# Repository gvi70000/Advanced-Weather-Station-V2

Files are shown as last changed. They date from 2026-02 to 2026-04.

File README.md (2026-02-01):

Advanced Weather Station V2
The Advanced Weather Station V2 is a high-precision environmental monitoring system designed for professional-grade reliability and scientific accuracy. Building upon the success of the first version, V2 introduces significant hardware optimizations and a more powerful processing architecture to deliver even better performance in the field.
TOP
BOTTOM

Key Improvements in V2
Upgraded MCU: Now powered by the STM32G431, providing enhanced processing capabilities, better power efficiency, and advanced peripherals compared to the previous generation.

Streamlined Communication: All Programmable Gain Amplifiers (PGAs) are now consolidated on a single UART bus, simplifying the communication protocol and reducing cable complexity.

Enhanced PCB Design: A completely overhauled PCB layout featuring improved signal integrity, better thermal management, and a more compact, robust form factor for long-term outdoor deployment.

Overview
This weather station integrates a comprehensive suite of high-precision sensors to monitor atmospheric conditions, air quality, and spatial positioning. It leverages ultrasonic technology for maintenance-free wind measurement and GNSS RTK for centimetre-level location accuracy.

Features & Sensors
Ultrasonic Wind Measurement: Precise wind speed and direction without moving parts.

GNSS RTK: High-precision positioning for mobile or stationary research.

Environmental Suite:

UV & Ambient Light: UV radiation and light intensity monitoring.

Air Quality: ScioSense ENS160 for CO2 and VOC detection.

Lightning Detection: ScioSense AS3935 for storm activity tracking.

Pressure & Temp: Bosch BMP581 for barometric accuracy.

Humidity: Dual TI HDC3020 sensors for redundant climate analysis.

Rugged Construction: Optical sensors are protected by UV-transparent glass, and the ultrasonic assembly uses 304 stainless steel and ASA 3D-printed enclosures.

Workflow
Data Acquisition: Sensors collect raw environmental data, including wind vectors, gas concentrations, and radiation levels.

Processing: The STM32G431 aggregates the data, applies calibration constants, and handles temperature compensation in real-time.

Connectivity: Processed data is transmitted via an ESP32-PoE interface to Ethernet networks, enabling seamless integration with MQTT brokers or cloud-based dashboards.

Applications
Climate & Scientific Research: Accurate data collection for long-term studies.

Smart Agriculture: Optimize irrigation and crop protection based on hyper-local weather.

Renewable Energy: Ideal for solar tracking and wind farm site assessment.

Smart Cities: Real-time air quality and environmental safety monitoring.

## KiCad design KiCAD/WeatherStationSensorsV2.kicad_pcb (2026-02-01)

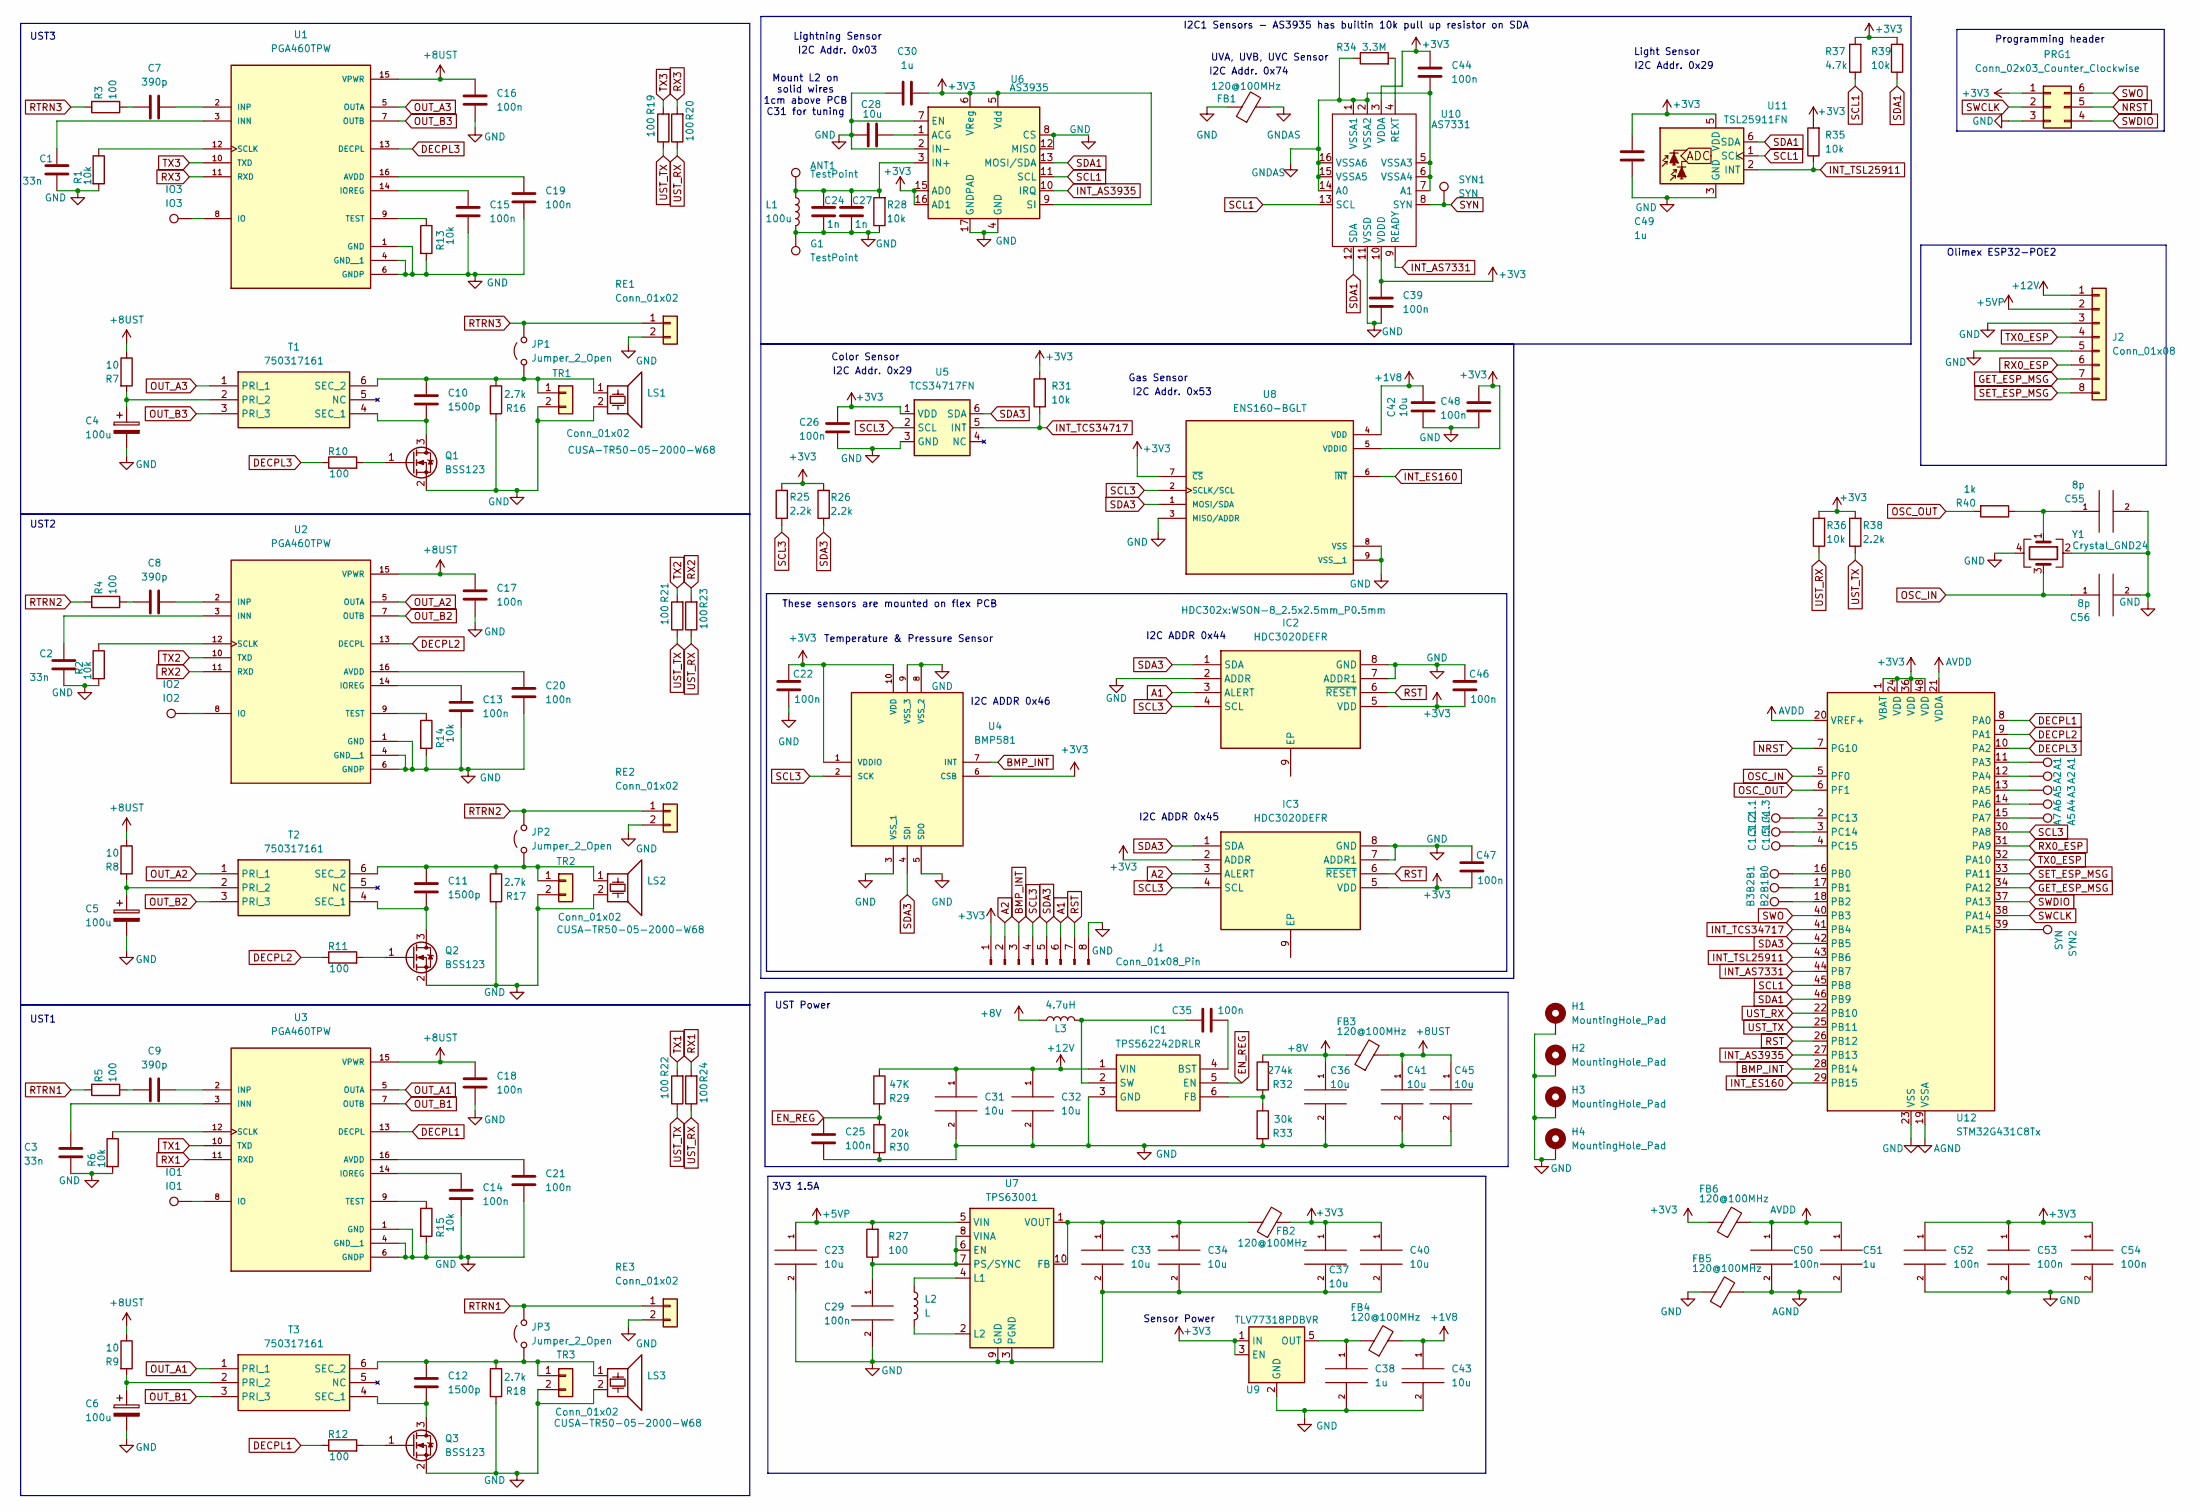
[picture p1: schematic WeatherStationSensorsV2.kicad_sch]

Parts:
A1: A1; TestPoint_Pad_D1.0mm
A2: A2; TestPoint_Pad_D1.0mm
A3: A5; TestPoint_Pad_D1.0mm
A4: A6; TestPoint_Pad_D1.0mm
A5: A7; TestPoint_Pad_D1.0mm
ANT1: TestPoint; TestPoint_THTPad_D1.5mm_Drill0.7mm
B1: B0; TestPoint_Pad_D1.0mm
B2: B1; TestPoint_Pad_D1.0mm
B3: B2; TestPoint_Pad_D1.0mm
C1, C2, C3: 33n; C_0805_2012Metric_Pad1.18x1.45mm_HandSolder
C1.1: C1.3; TestPoint_Pad_D1.0mm
C1.2: C1.4; TestPoint_Pad_D1.0mm
C1.3: C1.5; TestPoint_Pad_D1.0mm
C4, C5, C6: 100u; CP_Radial_D8.0mm_P3.50mm
C7, C8, C9: 390p; C_0805_2012Metric_Pad1.18x1.45mm_HandSolder
C10, C11, C12: 1500p; C_0805_2012Metric_Pad1.18x1.45mm_HandSolder
C13, C14, C15, C16, C17, C18, C19, C20, C21, C25, C26, C29, C35, C39, C44, C48, C50, C52, C53, C54: 100n; C_0805_2012Metric_Pad1.18x1.45mm_HandSolder
C22, C46, C47: 100n; C_0805_2012Metric
C23, C31, C32, C33, C34, C36, C37, C40, C41, C43, C45: 10u; C_1210_3225Metric_Pad1.33x2.70mm_HandSolder
C24, C27: 1n; C_0805_2012Metric_Pad1.18x1.45mm_HandSolder
C28, C42: 10u; C_0805_2012Metric_Pad1.18x1.45mm_HandSolder
C30, C38, C49, C51: 1u; C_0805_2012Metric_Pad1.18x1.45mm_HandSolder
C55, C56: 8p; C_0603_1608Metric_Pad1.08x0.95mm_HandSolder
FB1, FB2, FB3, FB4, FB5, FB6: 120@100MHz; R_0805_2012Metric_Pad1.20x1.40mm_HandSolder
G1: TestPoint; TestPoint_THTPad_D1.5mm_Drill0.7mm
H1, H2, H3, H4: MountingHole_Pad; MountingHole_3.2mm_M3_Pad_Via
IC1: TPS562242DRLR; SOTFL50P160X60-6N; Manufacturer_Part_Number TPS562242DRLR
IC2, IC3: HDC3020DEFR; WSON-8_2.5x2.5mm_P0.5mm; Mouser Part Number 595-HDC3020DEFR
IO1: IO1; TestPoint_Pad_D1.0mm
IO2: IO2; TestPoint_Pad_D1.0mm
IO3: IO3; TestPoint_Pad_D1.0mm
J1: Conn_01x08_Pin; Hirose_DF13-08P-1.25DSA_1x08_P1.25mm_Vertical
J2: Conn_01x08; PinHeader_1x08_P2.54mm_Vertical
JP1, JP2, JP3: Jumper_2_Open; SolderJumper-2_P1.3mm_Open_RoundedPad1.0x1.5mm
L1: 100u; Coilcraft_MA5532-AE_RFID
L2: L; CC453232A
L3: 4.7uH; L_Bourns_SDR0703-4R7KL
LS1, LS2, LS3: CUSA-TR50-05-2000-W68
PRG1: Conn_02x03_Counter_Clockwise; PinHeader_2x03_P2.54mm_Vertical
Q1, Q2, Q3: BSS123; SOT-23
R1, R2, R6, R13, R14, R15, R31, R35, R36, R39: 10k; R_0805_2012Metric_Pad1.20x1.40mm_HandSolder
R3, R4, R5, R10, R11, R12, R19, R20, R21, R22, R23, R24, R27: 100; R_0805_2012Metric_Pad1.20x1.40mm_HandSolder
R7, R8, R9: 10; R_0805_2012Metric_Pad1.20x1.40mm_HandSolder
R16, R17, R18: 2.7k; R_0805_2012Metric_Pad1.20x1.40mm_HandSolder
R25, R26, R38: 2.2k; R_0805_2012Metric_Pad1.20x1.40mm_HandSolder
R28: 10k; R_0603_1608Metric_Pad0.98x0.95mm_HandSolder
R29: 47K; R_0805_2012Metric_Pad1.20x1.40mm_HandSolder
R30: 20k; R_0805_2012Metric_Pad1.20x1.40mm_HandSolder
R32: 274k; R_0805_2012Metric_Pad1.20x1.40mm_HandSolder
R33: 30k; R_0805_2012Metric_Pad1.20x1.40mm_HandSolder
R34: 3.3M; R_0805_2012Metric_Pad1.20x1.40mm_HandSolder
R37: 4.7k; R_0805_2012Metric_Pad1.20x1.40mm_HandSolder
R40: 1k; R_0603_1608Metric_Pad0.98x0.95mm_HandSolder
RE1, RE2, RE3: Conn_01x02; PinHeader_1x02_P2.54mm_Vertical
SYN1, SYN2: SYN; TestPoint_Pad_D1.0mm
T1, T2, T3: 750317161; Mouser Part Number 710-750317161
TR1, TR2, TR3: Conn_01x02; PinHeader_1x02_P2.54mm_Vertical
U1, U2, U3: PGA460TPW; SOP65P640X120-16N; PARTREV B
U4: BMP581; Manufacturer_Part_Number BMP581
U5: TCS34717FN; FN6
U6: AS3935; MLPQ-16-1EP_4x4mm_P0.65mm_EP2.8x2.8mm
U7: TPS63001; Texas_DRC0010J_ThermalVias
U8: ENS160-BGLT; XDCR_ENS160-BGLT; PARTREV 1.3
U9: TLV77318PDBVR; SOT-23-5
U10: AS7331
U11: TSL25911FN; AMS_TSL25911FN
U12: STM32G431C8Tx; LQFP-48_7x7mm_P0.5mm
Y1: Crystal_GND24; Crystal_SMD_3225-4Pin_3.2x2.5mm_HandSoldering

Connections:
+1V8: C42.2, C43.1, FB4.2, U8.4 (VDD)
+3V3: C22.1, C26.1, C30.2, C37.1, C39.1, C40.1, C44.1, C46.2, C47.2, C48.1, C49.2, C52.1, C53.1, C54.1, FB2.2, FB6.1, IC2.5 (VDD), IC3.2 (ADDR), IC3.5 (VDD), J1.1, PRG1.1, R25.2, R26.2, R31.2, R35.2, R36.2, R37.2, R38.2, R39.2, U4.1 (VDDIO), U4.6 (CSB), U4.10 (VDD), U5.1 (VDD), U6.5 (Vdd), U6.6 (VReg), U6.9 (SI), U6.15 (AD0), U6.16 (AD1), U8.5 (VDDIO), U8.7 (~CS), U9.1 (IN), U9.3 (EN), U10.3 (VDDA), U10.10 (VDDD), U11.5 (VDD), U12.1 (VBAT), U12.24 (VDD), U12.36 (VDD), U12.48 (VDD)
+5VP: C23.1, J2.2, R27.2, U7.5 (VIN)
+8UST: C16.1, C17.1, C18.1, C41.1, C45.1, FB3.2, R7.1, R8.1, R9.1, U1.15 (VPWR), U2.15 (VPWR), U3.15 (VPWR)
+8V: C36.1, FB3.1, L3.1, R32.1
+12V: C31.1, C32.1, IC1.1 (VIN), J2.1, R29.1
A1: IC2.3 (ALERT), J1.6
A2: IC3.3 (ALERT), J1.2
AGND: C50.2, C51.2, FB5.2, U12.19 (VSSA)
AVDD: C50.1, C51.1, FB6.2, U12.20 (VREF+), U12.21 (VDDA)
BMP_INT: J1.3, U4.7 (INT), U12.28 (PB14)
DECPL1: R12.1, U3.13 (DECPL), U12.8 (PA0)
DECPL2: R11.1, U2.13 (DECPL), U12.9 (PA1)
DECPL3: R10.1, U1.13 (DECPL), U12.10 (PA2)
EN_REG: C25.1, IC1.5 (EN), R29.2, R30.1
GET_ESP_MSG: J2.7, U12.34 (PA12)
GND: C1.1, C2.1, C3.1, C4.2, C5.2, C6.2, C13.2, C14.2, C15.2, C16.2, C17.2, C18.2, C19.2, C20.2, C21.2, C22.2, C23.2, C24.2, C25.2, C26.2, C27.2, C28.2, C29.2, C30.1, C31.2, C32.2, C33.2, C34.2, C36.2, C37.2, C38.2, C39.2, C40.2, C41.2, C42.1, C43.2, C45.2, C46.1, C47.1, C48.2, C49.1, C52.2, C53.2, C54.2, C55.2, C56.2, FB1.1, FB5.1, G1.1, H1.1, H2.1, H3.1, H4.1, IC1.3 (GND), IC2.2 (ADDR), IC2.7 (ADDR1), IC2.8 (GND), IC3.7 (ADDR1), IC3.8 (GND), J1.8, J2.3, J2.5, L1.2, LS1.2, LS2.2, LS3.2, PRG1.3, Q1.2 (S), Q2.2 (S), Q3.2 (S), R1.2, R2.2, R6.2, R13.2, R14.2, R15.2, R16.2, R17.2, R18.2, R28.1, R30.2, R33.2, RE1.2, RE2.2, RE3.2, TR1.2, TR2.2, TR3.2, U1.1 (GND), U1.4 (GND__1), U1.6 (GNDP), U2.1 (GND), U2.4 (GND__1), U2.6 (GNDP), U3.1 (GND), U3.4 (GND__1), U3.6 (GNDP), U4.3 (VSS_1), U4.5 (SDO), U4.8 (VSS_2), U4.9 (VSS_3), U5.3 (GND), U6.2 (IN-), U6.4 (GND), U6.7 (EN), U6.8 (CS), U6.12 (MISO), U6.17 (GNDPAD), U7.3 (PGND), U7.9 (GND), U7.11 (PGND), U8.3 (MISO/ADDR), U8.8 (VSS), U8.9 (VSS__1), U9.2 (GND), U10.11 (VSSD), U11.3 (GND), U12.23 (VSS), U12.35 (VSS), U12.47 (VSS), Y1.2, Y1.4
GNDAS: C44.2, FB1.2, R34.1, U10.1 (VSSA1), U10.2 (VSSA2), U10.5 (VSSA3), U10.6 (VSSA4), U10.7 (A1), U10.14 (A0), U10.15 (VSSA5), U10.16 (VSSA6)
INT_AS3935: U6.10 (IRQ), U12.27 (PB13)
INT_AS7331: U10.9 (READY), U12.44 (PB7)
INT_ES160: U8.6 (~INT), U12.29 (PB15)
INT_TCS34717: R31.1, U5.5 (INT), U12.41 (PB4)
INT_TSL25911: R35.1, U11.2 (INT), U12.43 (PB6)
NRST: PRG1.5, U12.7 (PG10)
unnamed: C7.2, R3.1
unnamed: C8.2, R4.1
unnamed: C9.2, R5.1
unnamed: C55.1, R40.1, Y1.1
unnamed: C35.2, IC1.4 (BST)
unnamed: IC1.6 (FB), R32.2, R33.1
unnamed: C35.1, IC1.2 (SW), L3.2
unnamed: C10.1, JP1.1 (A), LS1.1, R16.1, T1.6 (SEC_2), TR1.1
unnamed: C11.1, JP2.1 (A), LS2.1, R17.1, T2.6 (SEC_2), TR2.1
unnamed: C12.1, JP3.1 (A), LS3.1, R18.1, T3.6 (SEC_2), TR3.1
unnamed: C10.2, Q1.3 (D), T1.4 (SEC_1)
unnamed: Q1.1 (G), R10.2
unnamed: C11.2, Q2.3 (D), T2.4 (SEC_1)
unnamed: Q2.1 (G), R11.2
unnamed: C12.2, Q3.3 (D), T3.4 (SEC_1)
unnamed: Q3.1 (G), R12.2
unnamed: C4.1, R7.2, T1.2 (PRI_2)
unnamed: C5.1, R8.2, T2.2 (PRI_2)
unnamed: C6.1, R9.2, T3.2 (PRI_2)
unnamed: C19.1, U1.16 (AVDD)
unnamed: C1.2, U1.3 (INN)
unnamed: C7.1, U1.2 (INP)
unnamed: IO3.1, U1.8 (IO)
unnamed: C15.1, U1.14 (IOREG)
unnamed: R1.1, U1.12 (SCLK)
unnamed: R13.1, U1.9 (TEST)
unnamed: C20.1, U2.16 (AVDD)
unnamed: C2.2, U2.3 (INN)
unnamed: C8.1, U2.2 (INP)
unnamed: IO2.1, U2.8 (IO)
unnamed: C13.1, U2.14 (IOREG)
unnamed: R2.1, U2.12 (SCLK)
unnamed: R14.1, U2.9 (TEST)
unnamed: C21.1, U3.16 (AVDD)
unnamed: C3.2, U3.3 (INN)
unnamed: C9.1, U3.2 (INP)
unnamed: IO1.1, U3.8 (IO)
unnamed: C14.1, U3.14 (IOREG)
unnamed: R6.1, U3.12 (SCLK)
unnamed: R15.1, U3.9 (TEST)
unnamed: C28.1, U6.1 (ACG)
unnamed: ANT1.1, C24.1, C27.1, L1.1, R28.2, U6.3 (IN+)
unnamed: C29.1, R27.1, U7.6 (EN), U7.7 (PS/SYNC), U7.8 (VINA)
unnamed: C33.1, C34.1, FB2.1, U7.1 (VOUT), U7.10 (FB)
unnamed: L2.1, U7.4 (L1)
unnamed: L2.2, U7.2 (L2)
unnamed: C38.1, FB4.1, U9.5 (OUT)
unnamed: R34.2, U10.4 (REXT)
unnamed: A1.1, U12.11 (PA3)
unnamed: A2.1, U12.12 (PA4)
unnamed: A3.1, U12.13 (PA5)
unnamed: A4.1, U12.14 (PA6)
unnamed: A5.1, U12.15 (PA7)
unnamed: SYN2.1, U12.39 (PA15)
unnamed: B1.1, U12.16 (PB0)
unnamed: B2.1, U12.17 (PB1)
unnamed: B3.1, U12.18 (PB2)
unnamed: C1.1.1, U12.2 (PC13)
unnamed: C1.2.1, U12.3 (PC14)
unnamed: C1.3.1, U12.4 (PC15)
OSC_IN: C56.1, U12.5 (PF0), Y1.3
OSC_OUT: R40.2, U12.6 (PF1)
OUT_A1: T3.1 (PRI_1), U3.5 (OUTA)
OUT_A2: T2.1 (PRI_1), U2.5 (OUTA)
OUT_A3: T1.1 (PRI_1), U1.5 (OUTA)
OUT_B1: T3.3 (PRI_3), U3.7 (OUTB)
OUT_B2: T2.3 (PRI_3), U2.7 (OUTB)
OUT_B3: T1.3 (PRI_3), U1.7 (OUTB)
RST: IC2.6 (~RESET), IC3.6 (~RESET), J1.7, U12.26 (PB12)
RTRN1: JP3.2 (B), R5.2, RE3.1
RTRN2: JP2.2 (B), R4.2, RE2.1
RTRN3: JP1.2 (B), R3.2, RE1.1
RX0_ESP: J2.6, U12.31 (PA9)
RX1: R24.2, U3.11 (RXD)
RX2: R23.2, U2.11 (RXD)
RX3: R20.2, U1.11 (RXD)
SCL1: R37.1, U6.11 (SCL), U10.13 (SCL), U11.1 (SCL), U12.45 (PB8)
SCL3: IC2.4 (SCL), IC3.4 (SCL), J1.4, R25.1, U4.2 (SCK), U5.2 (SCL), U8.2 (SCLK/SCL), U12.30 (PA8)
SDA1: R39.1, U6.13 (MOSI/SDA), U10.12 (SDA), U11.6 (SDA), U12.46 (PB9)
SDA3: IC2.1 (SDA), IC3.1 (SDA), J1.5, R26.1, U4.4 (SDI), U5.6 (SDA), U8.1 (MOSI/SDA), U12.42 (PB5)
SET_ESP_MSG: J2.8, U12.33 (PA11)
SWCLK: PRG1.2, U12.38 (PA14)
SWDIO: PRG1.4, U12.37 (PA13)
SWO: PRG1.6, U12.40 (PB3)
SYN: SYN1.1, U10.8 (SYN)
TX0_ESP: J2.4, U12.32 (PA10)
TX1: R22.2, U3.10 (TXD)
TX2: R21.2, U2.10 (TXD)
TX3: R19.2, U1.10 (TXD)
UST_RX: R20.1, R23.1, R24.1, R36.1, U12.22 (PB10)
UST_TX: R19.1, R21.1, R22.1, R38.1, U12.25 (PB11)

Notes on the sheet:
3V3 1.5A
These sensors are mounted on flex PCB
UST1
I2C Addr. 0x74
UST2
Gas Sensor
I2C Addr. 0x53
Mount L2 on solid wires 1cm above PCB C31 for tuning
Lightning Sensor
I2C ADDR 0x45
Sensor Power
Temperature & Pressure Sensor
I2C ADDR 0x44
Programming header
I2C Addr. 0x03
UST3
Light Sensor
UVA, UVB, UVC Sensor
I2C1 Sensors - AS3935 has builtin 10k pull up resistor on SDA
I2C Addr. 0x29
Olimex ESP32-POE2
UST Power
I2C ADDR 0x46
Color Sensor

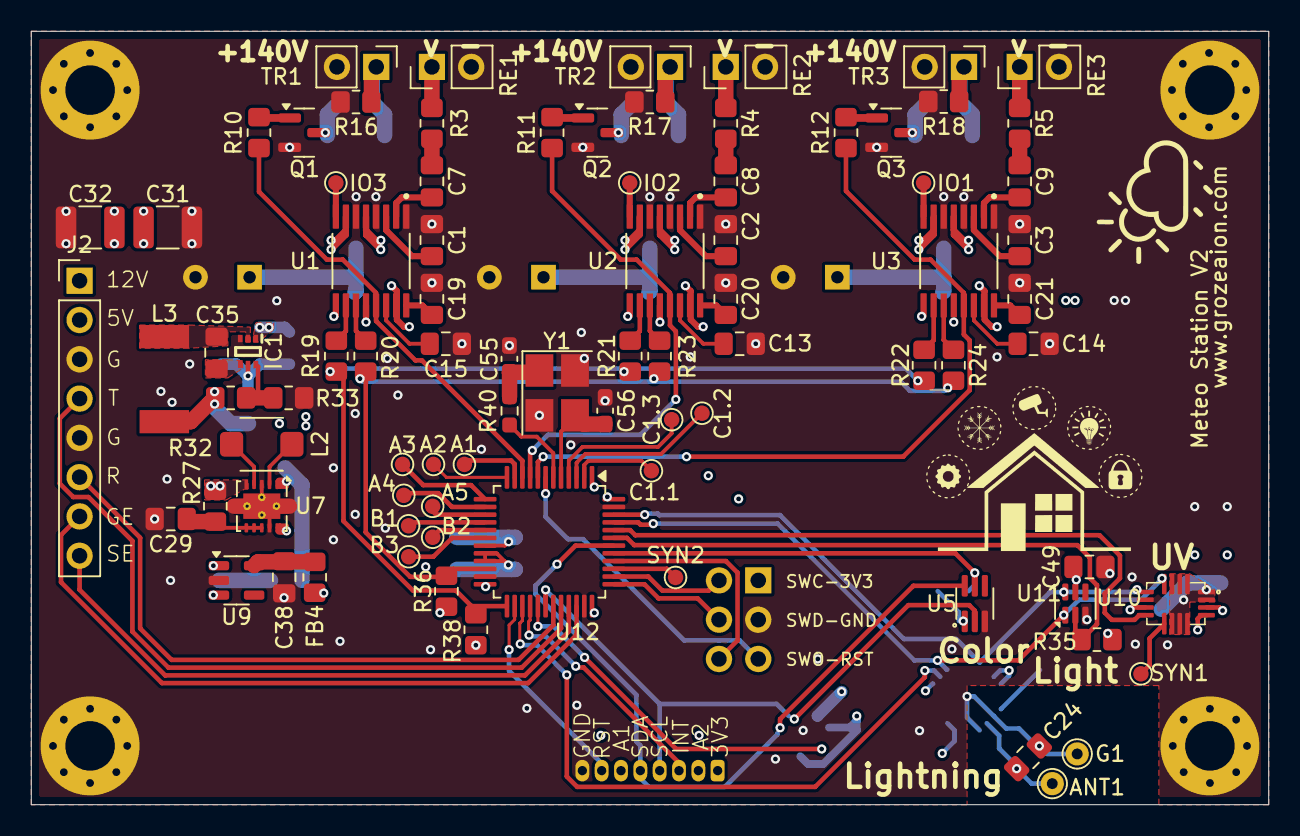
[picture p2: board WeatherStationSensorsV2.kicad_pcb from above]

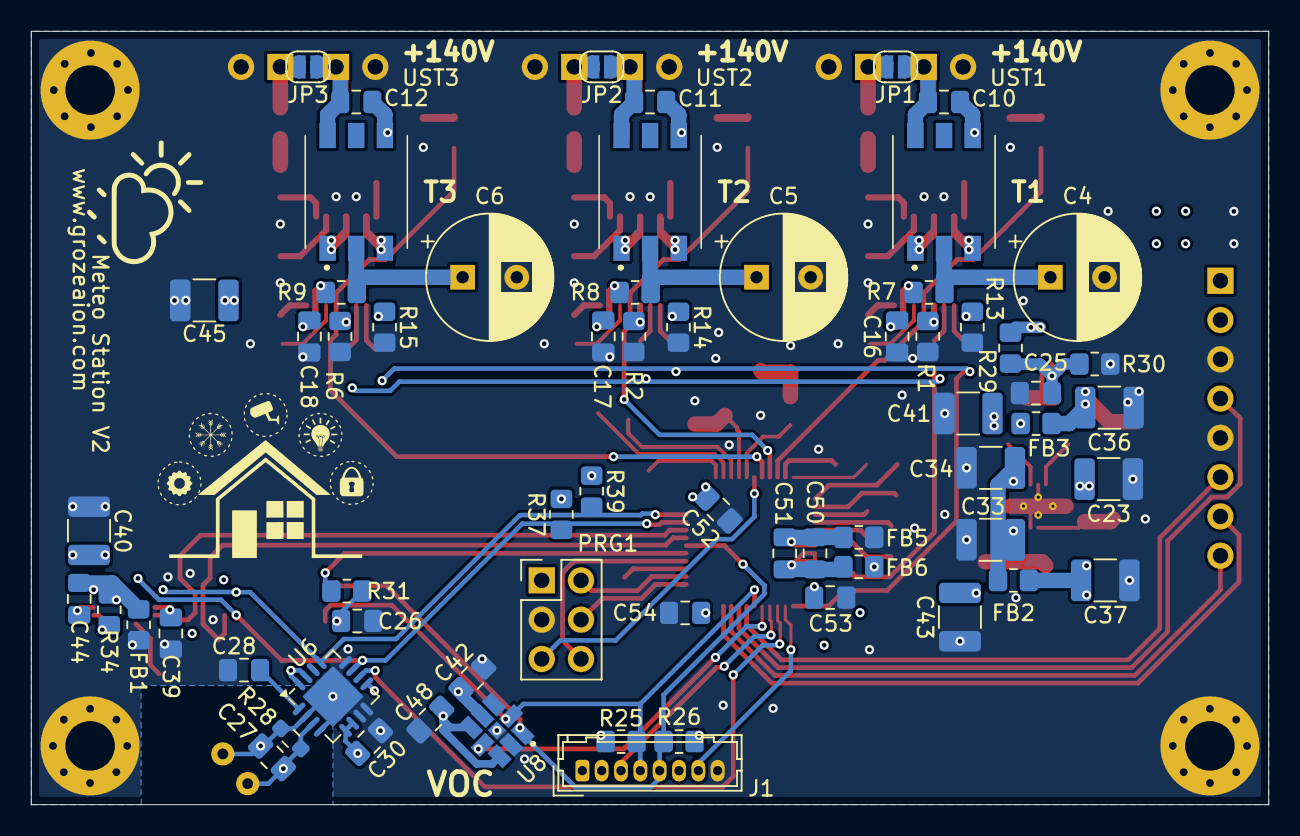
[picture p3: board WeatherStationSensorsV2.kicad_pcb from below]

Board: 4 copper layers, 80.0 x 50.0 mm, 154 parts (65 on the bottom side), 113 nets.

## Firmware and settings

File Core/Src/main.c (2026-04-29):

/**
  ******************************************************************************
  * @file           : main.c
  * @brief          : Main program body
  ******************************************************************************
  * @attention
  *
  * Copyright (c) 2026 STMicroelectronics.
  * All rights reserved.
  *
  * This software is licensed under terms that can be found in the LICENSE file
  * in the root directory of this software component.
  * If no LICENSE file comes with this software, it is provided AS-IS.
  *
  ******************************************************************************
  */
/* USER CODE END Header */
/* Includes ------------------------------------------------------------------*/
#include "main.h"
#include "cordic.h"
#include "dma.h"
#include "i2c.h"
#include "tim.h"
#include "usart.h"
#include "gpio.h"

/* USER CODE BEGIN Includes */
#include <stdio.h>
#include <string.h>
#include <math.h>
/* I2C3 sensors */
#include "BMP581.h"
#include "HDC302x.h"
#include "TCS34003.h"
#include "ENS160.h"
/* I2C1 sensors */
#include "TSL25911.h"
#include "AS7331.h"
#include "AS3935.h"
#include "PGA460.h"
#include "Wind.h"
#include "debug.h"
/* USER CODE END Includes */

/* USER CODE BEGIN PM */

/* =========================================================================
 * Sensor ready bitmasks
 * ======================================================================= */
#define SENSOR_ENV        (1u << 0)  /* BMP581 + HDC302x environmental data  */
#define SENSOR_AS7331     (1u << 1)  /* UV sensor                             */
#define SENSOR_ENS160     (1u << 2)  /* Air quality                           */
#define SENSOR_TCS34003   (1u << 3)  /* RGB colour                            */
#define SENSOR_TSL25911   (1u << 4)  /* Ambient light                         */
#define SENSOR_WIND       (1u << 5)  /* Wind (disabled — commented out below) */
#define SENSOR_AS3935     (1u << 6)  /* Lightning (preserved across frames)   */

/* Bits that must ALL be set before a sensor data frame is sent to the ESP.
 * SENSOR_WIND (bit 5) is excluded while wind measurement is disabled.
 * SENSOR_AS3935 (bit 6) is excluded — lightning is asynchronous and is
 * preserved in the payload until a new event overwrites it.               */
#define SENSOR_FRAME_MASK  0x1Fu     /* bits 0–4: ENV|AS7331|ENS160|TCS|TSL  */

/* =========================================================================
 * STM32 -> ESP  UART frame protocol
 *
 * Frame A — Sensor data (68 bytes):
 *   [0x23][0x40][Payload(64)][CRC16(2)]
 *   SOF = { 0x23, 0x40 }  (Start + Length byte, 0x40 = 64)
 *   CRC covers Payload only (64 bytes).
 *
 * Frame B — Wind calibration readback (17 bytes):
 *   [0x23][0x24][0x0C][D01(4)][D12(4)][D20(4)][CRC16(2)]
 *   SOF = { 0x23, 0x24 }  (Start + FrameType CAL)
 *   CRC covers Length byte + 3 x uint32 = 13 bytes.
 * ======================================================================= */
#define UART_FRAME_START   0x23u   /* '#'  first SOF byte for both TX frames  */
#define UART_FRAME_CAL     0x24u   /* '$'  second SOF byte for calibration TX */

/* =========================================================================
 * ESP -> STM  UART frame protocol
 *
 * Single frame type — 20 bytes:
 *   [0x23][FrameType(1)][Wind_Input_t(16)][CRC16(2)]
 *   CRC covers FrameType + Wind_Input_t = 17 bytes.
 *
 * FrameType values:
 *   0x24  UART_FRAME_CAL      Boot-time: ESP sends Height + D01/D12/D20 from NVS
 *   0x25  UART_FRAME_TMP      Height field carries float temperature reference (°C)
 *   0x26  UART_FRAME_RH       Height field carries float RH reference (%)
 *   0x27  UART_FRAME_RST      System reset request (Wind_Input_t payload ignored)
 *   0x28  UART_FRAME_CAL_REQ  Run Wind_CalibrateReflector() request
 * ======================================================================= */
#define UART_FRAME_TMP      0x25u   /* '%' temperature reference              */
#define UART_FRAME_RH       0x26u   /* '&' RH reference                       */
#define UART_FRAME_RST      0x27u   /* ''' reset                              */
#define UART_FRAME_CAL_REQ  0x28u   /* '(' calibration run request            */

/* ESP->STM frame size = Start(1) + FrameType(1) + Wind_Input_t(16) + CRC(2) */
#define UART_ESP_RX_SIZE   20u

/* =========================================================================
 * AS3935 interrupt type encoding in DistanceEstimation byte
 *
 * The AS3935_LightningData_t.DistanceEstimation byte carries two fields:
 *   Bits [5:0]  = distance code  (AS3935_Distance_t, 0x3F = out of range)
 *   Bits [7:4]  = interrupt type (AS3935_INT_t: 0x01=NH, 0x04=D, 0x08=L)
 *
 * Bits [7:6] of the raw register are reserved/always-zero per datasheet,
 * so packing the INT type there is non-destructive and backward-compatible
 * with any ESP code that masks off the upper nibble before reading distance.
 *
 * Helper macros:
 *   AS3935_ENCODE_DIST(irq, dist)  — pack for the wire
 *   AS3935_DECODE_INT(byte)        — extract INT type
 *   AS3935_DECODE_DIST(byte)       — extract distance code
 * ======================================================================= */
#define AS3935_ENCODE_DIST(irq, dist)  ((uint8_t)(((uint8_t)(irq) << 4) | ((dist) & 0x3Fu)))
#define AS3935_DECODE_INT(byte)        (((byte) >> 4) & 0x0Fu)
#define AS3935_DECODE_DIST(byte)       ((byte) & 0x3Fu)

/* =========================================================================
 * PID / sensor filtering constants
 * ======================================================================= */
#define DT_SEC             1.0f
#define TEMP_DEADBAND      0.2f
#define RH_DEADBAND        0.5f
#define MAX_TEMP_STEP      0.2f
#define MAX_RH_STEP        0.5f
#define TEMP_OFFSET_MIN   -1.0f
#define TEMP_OFFSET_MAX    1.0f
#define RH_OFFSET_MIN    -3.0f
#define RH_OFFSET_MAX     3.0f

/* USER CODE END PM */


/* USER CODE BEGIN PV */
/* Data-ready flags set by HAL_GPIO_EXTI_Callback (gpio.c) */
extern volatile uint8_t AS3935_Ready;
extern volatile uint8_t AS7331_Ready;
extern volatile uint8_t ENS160_Ready;
extern volatile uint8_t BMP_Ready;
extern volatile uint8_t TCS34003_Ready;
extern volatile uint8_t TSL25911_Ready;
extern volatile uint8_t ESP_Transmitting;

volatile uint8_t sensorReadyFlags = 0;

/* Shared environmental data — written by main loop, read by Wind.c */
extern Wind_EnvData_t externalData;

/* Sensor data structs */
BMP581_sensor_data_t BMP581_Data;
HDC302x_t            Sensor1;
HDC302x_t            Sensor2;
ENS160_Resistance_t  ENS160_Resistance;

/* Wind calibration data: Height, PathLenD01, PathLenD12, PathLenD20 */
extern Wind_Input_t calibData;

/* =========================================================================
 * UART_Payload_t — 64 bytes, must match ESP UART_Payload_t exactly.
 *
 * TCS34003: full TCS34003_LightData_t (22 B) is sent — RGBC(8) + IR(2)
 * + CCT(4) + Lux(4) + Irradiance(4).  All fields computed on STM and
 * published by ESP to individual MQTT topics.
 *
 * AS3935 note: LightningData_t.DistanceEstimation encodes both the INT type
 * (bits [7:4]) and the distance code (bits [5:0]).  See AS3935_ENCODE_DIST.
 * ======================================================================= */
typedef struct __attribute__((packed)) {
    Wind_EnvData_t       Env;          /* 20 B: Temp, RH, Pressure, DewPt, SndSpd */
    Wind_t               Wind;         /*  8 B: Speed (f32), Direction (f32)        */
    AS3935_LightningData_t Lightning;  /*  5 B: Energy (u32), DistanceEstimation(u8)*/
    AS7331_DataOut_t     UV;           /*  8 B: TEMP_C100, UVA, UVB, UVC (u16 x4)  */
    ENS160_Data_t        AirQuality;   /*  5 B: AQI (u8), TVOC (u16), eCO2 (u16)   */
    TCS34003_LightData_t LightRGB;     /* 22 B: RGBC(8)+IR(2)+CCT(4)+Lux(4)+Irr(4) */
    TSL25911_LightData_t Light;        /* 10 B: FS, IR, Vis (u16 x3), Lux (f32)    */
} UART_Payload_t;                      /* = 64 bytes total                          */

_Static_assert(sizeof(UART_Payload_t) == 78u,
    "UART_Payload_t size mismatch with ESP — check struct members");

/* =========================================================================
 * STM -> ESP sensor data frame.
 * Wire:  [0x23][0x4E][Payload(78)][CRC16(2)]  = 82 bytes.
 * ======================================================================= */
typedef struct __attribute__((packed)) {
    uint8_t        Start;    /* 0x23                              */
    uint8_t        Length;   /* sizeof(UART_Payload_t) = 64=0x40 */
    UART_Payload_t Payload;
    uint16_t       CR;       /* CRC16 over Payload only           */
} UART_TX_Frame_t;

_Static_assert(sizeof(UART_TX_Frame_t) == 82u,
    "UART_TX_Frame_t size mismatch with ESP");

/* =========================================================================
 * STM -> ESP calibration frame (after Wind_CalibrateReflector).
 * Wire:  [0x23][0x24][0x0C][D01(4)][D12(4)][D20(4)][CRC16(2)]  = 17 bytes.
 * CRC covers: Length(1) + D01(4) + D12(4) + D20(4) = 13 bytes.
 * ======================================================================= */
typedef struct __attribute__((packed)) {
    uint8_t  Start;       /* UART_FRAME_START 0x23          */
    uint8_t  FrameType;   /* UART_FRAME_CAL   0x24          */
    uint8_t  Length;      /* 3 * sizeof(uint32_t) = 12      */
    uint32_t PathLenD01;
    uint32_t PathLenD12;
    uint32_t PathLenD20;
    uint16_t CR;
} UART_TX_Cal_Frame_t;

_Static_assert(sizeof(UART_TX_Cal_Frame_t) == 17u,
    "UART_TX_Cal_Frame_t size mismatch");

/* =========================================================================
 * ESP -> STM command frame (all types share this layout).
 * Wire:  [0x23][FrameType(1)][Wind_Input_t(16)][CRC16(2)]  = 20 bytes.
 * CRC covers: FrameType(1) + Wind_Input_t(16) = 17 bytes.
 * ======================================================================= */
typedef struct __attribute__((packed)) {
    uint8_t      Start;      /* UART_FRAME_START 0x23                      */
    uint8_t      FrameType;  /* 0x24..0x28 — selects action                */
    Wind_Input_t Payload;    /* Wind_Input_t: Height(4), D01(4),D12(4),D20(4) */
    uint16_t     CR;         /* CRC16 over FrameType + Wind_Input_t        */
} UART_RX_Frame_t;

_Static_assert(sizeof(UART_RX_Frame_t) == 20u,
    "UART_RX_Frame_t size mismatch");

/* DMA buffers */
static UART_TX_Frame_t  txFrameBuf;
static uint8_t          espRxBuf[UART_ESP_RX_SIZE];

/* Runtime state */
static float            temperatureCalibrated = 0.0f;
static float            humidityCalibrated    = 0.0f;
static uint8_t          isReset               = 0;
static volatile uint8_t isCalibrate           = 0;
volatile uint8_t        dmaTxBusy             = 0;  /* extern in usart.c */
uint32_t                time                  = 0;

typedef struct {
    float kp, ki, kd;
    float integral;
    float prevError;
    float outMin, outMax;
    float errAvg;
    float errVar;
} PID_t;

PID_t pidTemp1 = { .kp = 0.3f,  .ki = 0.05f, .kd = 0.1f,  .outMin = -5.0f,  .outMax = 5.0f  };
PID_t pidTemp2 = { .kp = 0.3f,  .ki = 0.05f, .kd = 0.1f,  .outMin = -5.0f,  .outMax = 5.0f  };
PID_t pidRH    = { .kp = 0.2f,  .ki = 0.02f, .kd = 0.05f, .outMin = -10.0f, .outMax = 10.0f };

/* USER CODE END PV */

void SystemClock_Config(void);
/* USER CODE BEGIN 0 */

/* -------------------------------------------------------------------------
 * CRC16 (Modbus) — matches the ESP implementation exactly.
 * ---------------------------------------------------------------------- */
static uint16_t CRC16(const uint8_t *data, uint16_t len) {
    uint16_t crc = 0xFFFFu;
    for (uint16_t i = 0; i < len; i++) {
        crc ^= data[i];
        for (uint8_t j = 0; j < 8u; j++) {
            crc = (crc & 1u) ? ((crc >> 1) ^ 0xA001u) : (crc >> 1);
        }
    }
    return crc;
}

/* -------------------------------------------------------------------------
 * SendDataToESP — non-blocking DMA TX.
 *
 * Wire frame: [0x23][0x4E][Payload(78)][CRC16(2)] = 82 bytes.
 * The ESP processSTMbyte() syncs on the two-byte sequence {0x23, 0x4E}.
 * STM_START_TX asserts SET_ESP_MSG so the ESP backs off (FIX-3 on ESP side).
 * dmaTxBusy is cleared in HAL_UART_TxCpltCallback (usart.c) on DMA complete.
 * ---------------------------------------------------------------------- */
void SendDataToESP(void) {
    if (dmaTxBusy) return;
    txFrameBuf.CR = CRC16((const uint8_t *)&txFrameBuf.Payload,
                          sizeof(UART_Payload_t));
    dmaTxBusy = 1;
    STM_START_TX;
    HAL_UART_Transmit_DMA(&huart1, (uint8_t *)&txFrameBuf,
                          sizeof(UART_TX_Frame_t));
}
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
int main(void)
{

  /* MCU Configuration--------------------------------------------------------*/
  HAL_Init();

  /* Configure the system clock */
  SystemClock_Config();

  /* Initialize all configured peripherals */
  MX_GPIO_Init();
  MX_DMA_Init();
  MX_USART1_UART_Init();
  MX_TIM2_Init();
  MX_USART3_UART_Init();
  MX_I2C1_Init();
  MX_I2C3_Init();
  MX_CORDIC_Init();

  /* USER CODE BEGIN 2 */
#ifdef AS3935_MODE_IRQ
    Enable_EXTI_AS3935();
#endif /* AS3935_MODE_IRQ */

    /* Initialise TX frame fixed header fields */
    txFrameBuf.Start  = UART_FRAME_START;
    txFrameBuf.Length = (uint8_t)sizeof(UART_Payload_t);   /* 78 = 0x4E */

    /* Start DMA RX from ESP in circular mode — TC interrupt only */
    HAL_UART_Receive_DMA(&huart1, espRxBuf, UART_ESP_RX_SIZE);
    __HAL_DMA_DISABLE_IT(huart1.hdmarx, DMA_IT_HT);

    /* HDC302x temperature / humidity sensors */
    Sensor1.Address = HDC302X_SENSOR_1_ADDR;
    if (HDC302x_Init(&Sensor1) != HAL_OK) {
        DEBUG("Sensor 1 init failed!\n");
    } else {
        DEBUG("Sensor 1 init OK.\n");
    }
    Sensor2.Address = HDC302X_SENSOR_2_ADDR;
    if (HDC302x_Init(&Sensor2) != HAL_OK) {
        DEBUG("Sensor 2 init failed!\n");
    } else {
        DEBUG("Sensor 2 init OK.\n");
    }
    HDC302x_StartAutoMeasurement(&Sensor1, HDC302X_CMD_AUTO_MEASUREMENT_1_PER_SECOND_LPM0);
    HDC302x_StartAutoMeasurement(&Sensor2, HDC302X_CMD_AUTO_MEASUREMENT_1_PER_SECOND_LPM0);

    /* BMP581 pressure / temperature (interrupt-driven) */
    if (BMP581_Init() == HAL_OK) {
        DEBUG("BMP581 init OK!\n");
    } else {
        DEBUG("BMP581 init FAIL!\n");
    }

    /* ENS160 air quality */
    if (ENS160_Init() != HAL_OK) {
        DEBUG("ENS160 init failed!\n");
    }

    /* AS3935 lightning sensor */
    if (AS3935_Init() != HAL_OK) {
        DEBUG("AS3935 init failed!\n");
    }
#ifdef AS3935_MODE_CALIB
    else {
        /* Antenna tuning: TIM2 CH4 is configured for input capture in
         * CALIB mode.  Start the timer base then run the sweep.        */
        HAL_TIM_Base_Start(&htim2);
        DEBUG("_______________________\n");
        AS3935_TuneCap_t bestCap = AS3935_TuneAntenna();
        AS3935_SetTuningCapacitor(bestCap);
        HAL_TIM_Base_Stop(&htim2);
        DEBUG("AS3935 tuning done, cap=%d\n", (int)bestCap);
    }
#endif /* AS3935_MODE_CALIB */

    /* UV, colour and ambient light sensors */
    if (AS7331_Init()   != HAL_OK) { DEBUG("AS7331 init failed!\n");   }
    if (TCS34003_Init() != HAL_OK) { DEBUG("TCS34003 init failed!\n"); }
    if (TSL25911_Init() != HAL_OK) { DEBUG("TSL25911 init failed!\n"); }

    /* Wind measurement — uncomment when PGA460 hardware is fitted */
    /* PGA460_Init(0); */
    /* Wind_Init();    */

    time = HAL_GetTick();
  /* USER CODE END 2 */

  /* Infinite loop */
  /* USER CODE BEGIN WHILE */
  while (1)
  {
        /* --- System reset requested by ESP --- */
        if (isReset) {
            HAL_Delay(10);
            __NVIC_SystemReset();
        }

        /* --- Wind calibration requested by ESP (MQTT) --- */
        if (isCalibrate) {
            isCalibrate = 0;
            DEBUG("Calibration requested by ESP\n");
            if (Wind_CalibrateReflector() == HAL_OK) {
                SendCalibrationToESP();
            } else {
                DEBUG("Calibration FAILED\n");
            }
        }

        /* --- BMP581 + HDC302x (~1 Hz, BMP interrupt-driven) --- */
        if (BMP_Ready) {
            BMP_Ready = 0;
            float temp1 = 0.0f, temp2 = 0.0f, rh1 = 0.0f, rh2 = 0.0f;
            static float prevOutT1  = 0.0f, prevOutT2  = 0.0f;
            static float prevOutRH1 = 0.0f, prevOutRH2 = 0.0f;

            BMP581_Get_TempPressData(&BMP581_Data);
            if (HDC302x_ReadData(&Sensor1) == HAL_OK) { temp1 = Sensor1.Data.Temperature; rh1 = Sensor1.Data.Humidity; }
            if (HDC302x_ReadData(&Sensor2) == HAL_OK) { temp2 = Sensor2.Data.Temperature; rh2 = Sensor2.Data.Humidity; }

            /* Temperature PID */
            float tempRef = (temperatureCalibrated != 0.0f) ? temperatureCalibrated : BMP581_Data.temperature;
            float errT1 = tempRef - temp1; if (fabsf(errT1) < TEMP_DEADBAND) errT1 = 0.0f;
            float errT2 = tempRef - temp2; if (fabsf(errT2) < TEMP_DEADBAND) errT2 = 0.0f;
            float outT1 = PID_Update_Adaptive(&pidTemp1, errT1, DT_SEC);
            float outT2 = PID_Update_Adaptive(&pidTemp2, errT2, DT_SEC);
            float dT1 = outT1 - prevOutT1;
            if (dT1 >  MAX_TEMP_STEP) outT1 = prevOutT1 + MAX_TEMP_STEP;
            if (dT1 < -MAX_TEMP_STEP) outT1 = prevOutT1 - MAX_TEMP_STEP;
            float dT2 = outT2 - prevOutT2;
            if (dT2 >  MAX_TEMP_STEP) outT2 = prevOutT2 + MAX_TEMP_STEP;
            if (dT2 < -MAX_TEMP_STEP) outT2 = prevOutT2 - MAX_TEMP_STEP;
            prevOutT1 = outT1; prevOutT2 = outT2;
            if (outT1 > TEMP_OFFSET_MAX) outT1 = TEMP_OFFSET_MAX;
            if (outT1 < TEMP_OFFSET_MIN) outT1 = TEMP_OFFSET_MIN;
            if (outT2 > TEMP_OFFSET_MAX) outT2 = TEMP_OFFSET_MAX;
            if (outT2 < TEMP_OFFSET_MIN) outT2 = TEMP_OFFSET_MIN;

            /* Humidity PID */
            float rhRef = (humidityCalibrated != 0.0f) ? humidityCalibrated : (rh1 + rh2) * 0.5f;
            float errRH1 = rhRef - rh1; if (fabsf(errRH1) < RH_DEADBAND) errRH1 = 0.0f;
            float errRH2 = rhRef - rh2; if (fabsf(errRH2) < RH_DEADBAND) errRH2 = 0.0f;
            float outRH1 = PID_Update_Adaptive(&pidRH, errRH1, DT_SEC);
            float outRH2 = PID_Update_Adaptive(&pidRH, errRH2, DT_SEC);
            float dRH1 = outRH1 - prevOutRH1;
            if (dRH1 >  MAX_RH_STEP) outRH1 = prevOutRH1 + MAX_RH_STEP;
            if (dRH1 < -MAX_RH_STEP) outRH1 = prevOutRH1 - MAX_RH_STEP;
            float dRH2 = outRH2 - prevOutRH2;
            if (dRH2 >  MAX_RH_STEP) outRH2 = prevOutRH2 + MAX_RH_STEP;
            if (dRH2 < -MAX_RH_STEP) outRH2 = prevOutRH2 - MAX_RH_STEP;
            prevOutRH1 = outRH1; prevOutRH2 = outRH2;
            if (outRH1 > RH_OFFSET_MAX) outRH1 = RH_OFFSET_MAX;
            if (outRH1 < RH_OFFSET_MIN) outRH1 = RH_OFFSET_MIN;
            if (outRH2 > RH_OFFSET_MAX) outRH2 = RH_OFFSET_MAX;
            if (outRH2 < RH_OFFSET_MIN) outRH2 = RH_OFFSET_MIN;

            HDC302x_SetOffset(&Sensor1, outT1, outRH1);
            HDC302x_SetOffset(&Sensor2, outT2, outRH2);

            txFrameBuf.Payload.Env.Temperature = (temp1 + outT1 + temp2 + outT2) * 0.5f;
            txFrameBuf.Payload.Env.RH          = (rh1 + outRH1 + rh2 + outRH2) * 0.5f;
            txFrameBuf.Payload.Env.Pressure    = BMP581_Data.pressure;

            ENS160_SetEnvCompensation(txFrameBuf.Payload.Env.Temperature,
                                      txFrameBuf.Payload.Env.RH);

            externalData.Temperature = txFrameBuf.Payload.Env.Temperature;
            externalData.RH          = txFrameBuf.Payload.Env.RH;
            externalData.Pressure    = txFrameBuf.Payload.Env.Pressure;
            Wind_ComputeSoundSpeed();
            txFrameBuf.Payload.Env.DewPoint   = externalData.DewPoint;
            txFrameBuf.Payload.Env.SoundSpeed = externalData.SoundSpeed;

            sensorReadyFlags |= SENSOR_ENV;
        }

        /* --- AS3935 lightning sensor (EXTI interrupt-driven) ---
         *
         * AS3935_GetInterruptType() reads the INT register and handles the
         * mandatory >= 2 ms post-IRQ delay internally.
         *
         * All three interrupt types are forwarded to the ESP so it can publish
         * each event to its own MQTT topic.  The interrupt type is packed into
         * bits [7:4] of DistanceEstimation (bits [5:0] carry the distance code;
         * bits [7:6] are reserved-zero in the raw register).
         *
         * INT_L  (0x08) — real lightning strike: read energy + distance.
         * INT_D  (0x04) — disturber detected: no valid distance, send 0x3F.
         * INT_NH (0x01) — noise floor too high: no valid distance, send 0x3F.
         *
         * SENSOR_AS3935 is set on every interrupt so the ESP receives an
         * up-to-date event in the next regular sensor frame.
         * The flag is preserved (not cleared) after each frame send so the
         * last lightning reading persists in the payload until overwritten.  */
        if (AS3935_Ready) {
            AS3935_Ready = 0;
            AS3935_INT_t irqType = AS3935_GetInterruptType();
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

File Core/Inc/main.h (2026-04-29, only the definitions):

#define TIMEOUT_COMM            100 // Timeout for sending ModBus frames
#define DECPL0_Pin GPIO_PIN_0
#define DECPL0_GPIO_Port GPIOA
#define DECPL1_Pin GPIO_PIN_1
#define DECPL1_GPIO_Port GPIOA
#define DECPL2_Pin GPIO_PIN_2
#define DECPL2_GPIO_Port GPIOA
#define INT_AS3935_Pin GPIO_PIN_3
#define INT_AS3935_GPIO_Port GPIOA
#define INT_AS3935_EXTI_IRQn EXTI3_IRQn
#define SGN_Pin GPIO_PIN_5
#define SGN_GPIO_Port GPIOA
#define UST_RX_Pin GPIO_PIN_10
#define UST_RX_GPIO_Port GPIOB
#define UST_TX_Pin GPIO_PIN_11
#define UST_TX_GPIO_Port GPIOB
#define RST_HDC_Pin GPIO_PIN_12
#define RST_HDC_GPIO_Port GPIOB
#define BMP_INT_Pin GPIO_PIN_14
#define BMP_INT_GPIO_Port GPIOB
#define BMP_INT_EXTI_IRQn EXTI15_10_IRQn
#define INT_ES160_Pin GPIO_PIN_15
#define INT_ES160_GPIO_Port GPIOB
#define INT_ES160_EXTI_IRQn EXTI15_10_IRQn
#define ESP_RX_Pin GPIO_PIN_9
#define ESP_RX_GPIO_Port GPIOA
#define ESP_TX_Pin GPIO_PIN_10
#define ESP_TX_GPIO_Port GPIOA
#define SET_ESP_MSG_Pin GPIO_PIN_11
#define SET_ESP_MSG_GPIO_Port GPIOA
#define INT_TCS34003_Pin GPIO_PIN_4
#define INT_TCS34003_GPIO_Port GPIOB
#define INT_TCS34003_EXTI_IRQn EXTI4_IRQn
#define INT_TSL25911_Pin GPIO_PIN_6
#define INT_TSL25911_GPIO_Port GPIOB
#define INT_TSL25911_EXTI_IRQn EXTI9_5_IRQn
#define INT_AS7331_Pin GPIO_PIN_7
#define INT_AS7331_GPIO_Port GPIOB
#define INT_AS7331_EXTI_IRQn EXTI9_5_IRQn
#define AS3935_MODE_IRQ       /* <-- swap to AS3935_MODE_CALIB for tuning */
#define HDC_RST_On RST_HDC_GPIO_Port->BSRR = (uint32_t)RST_HDC_Pin;
#define HDC_RST_Off RST_HDC_GPIO_Port->BRR = (uint32_t)RST_HDC_Pin;
#define STM_START_TX	SET_ESP_MSG_GPIO_Port->BSRR = (uint32_t)SET_ESP_MSG_Pin;
#define STM_STOP_TX		SET_ESP_MSG_GPIO_Port->BRR	= (uint32_t)SET_ESP_MSG_Pin;

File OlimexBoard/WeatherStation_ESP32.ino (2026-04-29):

/**
 * @file WeatherStation_ESP32.ino
 * @brief Olimex ESP32-POE2 (WROVER-E-N4R8) – Weather Station Gateway
 * @details Bridges an STM32 sensor array and a SparkFun LG290P RTK GNSS module
 * to an Ethernet network via MQTT and NTRIP.
 * @date 2026-04-28
 *
 * Fixes applied (2026-04-17):
 *  FIX-1  processSTMbyte()  – Clear static `prev` after sync detected.
 *  FIX-2  ntripLoop()       – ntripHdrBuf[] moved to file scope, zeroed on connect.
 *  FIX-3  mqttCallback()    – Retry loop when PIN_STM_IS_TX is HIGH.
 *  FIX-4  ntripLoop()       – Reset ntripLastGGA on new connection.
 *  FIX-5  gpsHardwareReset()– Post-reset delay extended to 2500 ms.
 *  FIX-6  packWindHeight()  – Centralised IEEE-754 memcpy helper.
 *  FIX-7  pub() float       – Guard against NaN/Inf before dtostrf().
 *  FIX-8  publishGPSStatus()– Null/empty check on NMEA sentence pointer.
 *  FIX-9  mqtt buffer       – setBufferSize increased to 512 bytes.
 *  FIX-10 OTA reconnect     – Reset otaStarted on Ethernet disconnect.
 *
 * Protocol alignment with STM32 main.c (2026-04-28):
 *  PROTO-1  Defined UART_FRAME_SOF_B0/B1, CAL_SOF_B0/B1, CAL_FRAME_SIZE,
 *           CAL_PAYLOAD_SIZE, Cal_Payload_t — previously undefined/missing.
 *  PROTO-2  Removed broken WIND_SOF/CMD_SOF raw-byte approach. All ESP→STM
 *           frames now use UART_TX_Frame_t: [0x23][FrameType][Wind_Input_t(16)][CRC16(2)].
 *  PROTO-3  sendWindInputToSTM() rewritten with FrameType = UART_FRAME_CAL.
 *  PROTO-4  sendCmdToSTM() rewritten: FrameType encodes command type,
 *           Height field carries the float value (matching STM HAL_UART_RxCpltCallback).
 *  PROTO-5  AS3935 interrupt type decoded from DistanceEstimation bits [7:4].
 *           New MQTT topic weather/LightningType publishes INT_NH/INT_D/INT_L.
 *           Existing weather/DistanceEstimation masked to bits [5:0].
 */

#ifndef ETH_PHY_TYPE
  #define ETH_PHY_TYPE   ETH_PHY_LAN8720
  #define ETH_PHY_ADDR   0
  #define ETH_PHY_MDC    23
  #define ETH_PHY_MDIO   18
  #define ETH_PHY_POWER  12
  #define ETH_CLK_MODE   ETH_CLOCK_GPIO0_OUT
#endif

#include <ETH.h>
#include <ArduinoOTA.h>
#include <Preferences.h>
#include <PubSubClient.h>
#include <SparkFun_LG290P_GNSS.h>
#include "mbedtls/base64.h"
#include <math.h>   // isfinite()

// ==========================================================================
// USER CONFIGURATION
// ==========================================================================

static const char* MQTT_SERVER    = "10.0.1.6";
static const uint16_t MQTT_PORT   = 1883;
static const char* MQTT_CLIENT_ID = "WeatherStation";
static const char* MQTT_USER      = "";
static const char* MQTT_PASS      = "";
static const char* OTA_HOSTNAME   = "WeatherStation";
static const char* OTA_PASSWORD   = "ota1234";

static const char* NTRIP_HOST               = "";
static const uint16_t NTRIP_PORT            = 2101;
static const char* NTRIP_MOUNTPOINT         = "";
static const char* NTRIP_USER               = "";
static const char* NTRIP_PASS               = "";
static const uint32_t NTRIP_GGA_INTERVAL_MS = 10000UL;

// ==========================================================================
// MQTT TOPICS
// ==========================================================================
/** @name MQTT Publication Topics */
///@{
static const char* TOPIC_TEMP     = "weather/Temperature";
static const char* TOPIC_RH       = "weather/RH";
static const char* TOPIC_PRES     = "weather/Pressure";
static const char* TOPIC_DP       = "weather/DewPoint";
static const char* TOPIC_SP       = "weather/SoundSpeed";
static const char* TOPIC_UVT      = "weather/UVTemperature";
static const char* TOPIC_UVA      = "weather/UVA";
static const char* TOPIC_UVB      = "weather/UVB";
static const char* TOPIC_UVC      = "weather/UVC";
static const char* TOPIC_LIGHT_C  = "weather/ClearChannel";
static const char* TOPIC_LIGHT_R  = "weather/RedChannel";
static const char* TOPIC_LIGHT_G  = "weather/GreenChannel";
static const char* TOPIC_LIGHT_B  = "weather/BlueChannel";
static const char* TOPIC_LIGHT_FS = "weather/FullSpectrum";
static const char* TOPIC_LIGHT_IR = "weather/Infrared";
static const char* TOPIC_LIGHT_VI = "weather/Visible";
static const char* TOPIC_LIGHT_LX = "weather/Lux";
static const char* TOPIC_LIGHT_IR = "weather/TCS_IR";
static const char* TOPIC_LIGHT_CT = "weather/CCT";
static const char* TOPIC_LIGHT_IX = "weather/Irradiance";
static const char* TOPIC_AQI      = "weather/AQI";
static const char* TOPIC_TVOC     = "weather/TVOC";
static const char* TOPIC_ECO      = "weather/eCO2";
static const char* TOPIC_WS       = "weather/WindSpeed";
static const char* TOPIC_WD       = "weather/WindDirection";
static const char* TOPIC_LE       = "weather/LightningEnergy";
static const char* TOPIC_LD       = "weather/DistanceEstimation"; /* bits [5:0] only */
static const char* TOPIC_LT       = "weather/LightningType";      /* INT_NH/INT_D/INT_L */
static const char* TOPIC_WIND_H   = "weather/Wind/Height";
static const char* TOPIC_WIND_D01 = "weather/Wind/PathD01";
static const char* TOPIC_WIND_D12 = "weather/Wind/PathD12";
static const char* TOPIC_WIND_D20 = "weather/Wind/PathD20";
static const char* TOPIC_STATUS   = "weather/status";
///@}

/** @name MQTT Command Topics */
///@{
static const char* CMD_STM_RESET   = "weather/cmd/Reset";
static const char* CMD_TEMP_CALIB  = "weather/cmd/TempCalib";
static const char* CMD_RH_CALIB    = "weather/cmd/RHCalib";
static const char* CMD_WIND_HEIGHT = "weather/cmd/Wind/Height";
static const char* CMD_WIND_D01    = "weather/cmd/Wind/PathD01";
static const char* CMD_WIND_D12    = "weather/cmd/Wind/PathD12";
static const char* CMD_WIND_D20    = "weather/cmd/Wind/PathD20";
static const char* CMD_GPS_HWRESET = "weather/cmd/GPS/HWReset";
static const char* SUB_CMD_WILDCARD = "weather/cmd/#";
///@}

// ==========================================================================
// PIN DEFINITIONS
// ==========================================================================
#define PIN_STM_RX    36  /**< UART RX from STM32 (10k pull-up)       */
#define PIN_STM_TX     4  /**< UART TX to STM32                        */
#define PIN_STM_IS_TX 35  /**< Input: HIGH while STM32 is transmitting */
#define PIN_GPS_RX    34  /**< UART RX from LG290P                     */
#define PIN_GPS_TX    32  /**< UART TX to LG290P                       */
#define PIN_GPS_RST    5  /**< Hardware reset for LG290P (10k pull-up) */

// ==========================================================================
// PROTOCOL CONSTANTS  (must match STM32 main.c exactly)
// ==========================================================================
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
